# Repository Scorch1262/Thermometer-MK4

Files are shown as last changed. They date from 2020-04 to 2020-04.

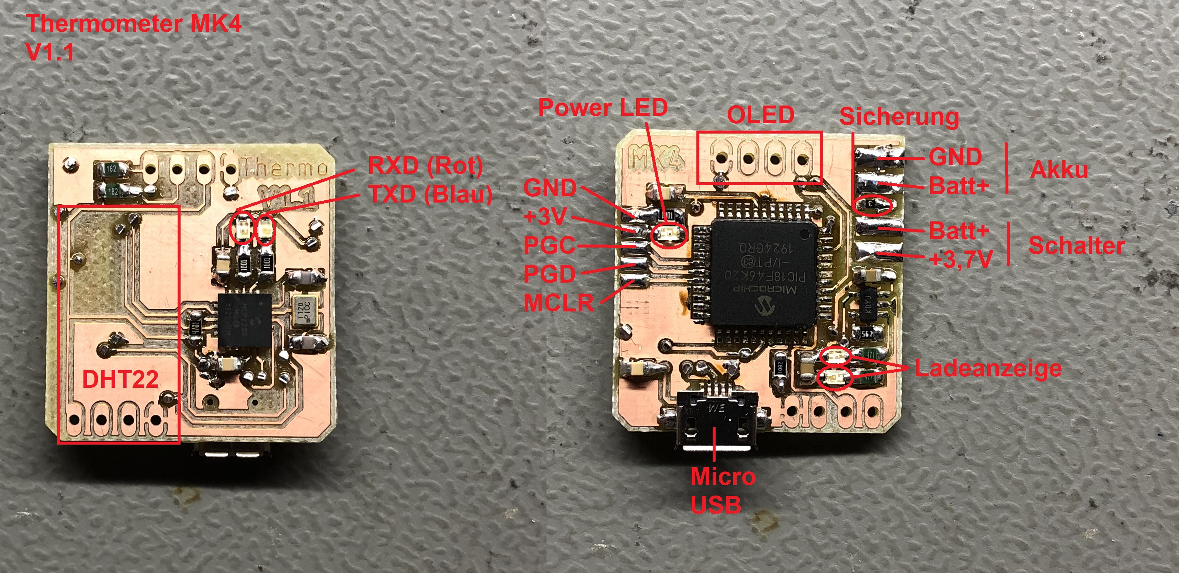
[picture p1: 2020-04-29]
Verkabelung V1.1.JPG

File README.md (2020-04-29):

Datenblatt

Status:				Fertig
Bezeichnung:			Thermometer MK4
Auftragsnummer:			
Auftraggeber:			Privat
Designer:			Torben Bott
Beschreibung:			Luftdruck und Themperatur Sensor mit OLED Anzeige, Lipo Akku und UART Schnittstelle 
			
Letzte Änderung:		23.04.2020

Versorgungsspannung (Normal):	5V
Versorgungsspannung (Min.):	5V
Versorgungsspannung (Max.):	5V
Interne Spannungen:		5V / 3,7V
		
Frequenz: 			16MHz
Prozessor: 			PIC18F46K20

Sensor:
https://github.com/jrmcguire/BME280

Display:
https://pic-projekte.de/blog/ssd1306/
https://github.com/PIC-Nico/SSD1306
https://pic-projekte.de/forum/viewtopic.php?f=3&t=104

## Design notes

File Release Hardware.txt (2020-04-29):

Hardware Release:

 Board (Hardware V1.1) [F]:
- PIC18F46K20
 - ISCP
- DHT22 Sensor
- LiPo Ladechip 
 - Status LEDs
- Power LED
- OLED-Display
- USB-UART Chip (MCP2200)
 - RXD LED
 - TXD LED
- Fehler behoben: Belegung DHT22
- Fehler behoben: UART Belegung

 Board (Hardware V1.0) [F]:
- PIC18F46K20
 - ISCP
- DHT22 Sensor
- LiPo Ladechip 
 - Status LEDs
- Power LED
- OLED-Display
- USB-UART Chip (MCP2200)
 - RXD LED
 - TXD LED

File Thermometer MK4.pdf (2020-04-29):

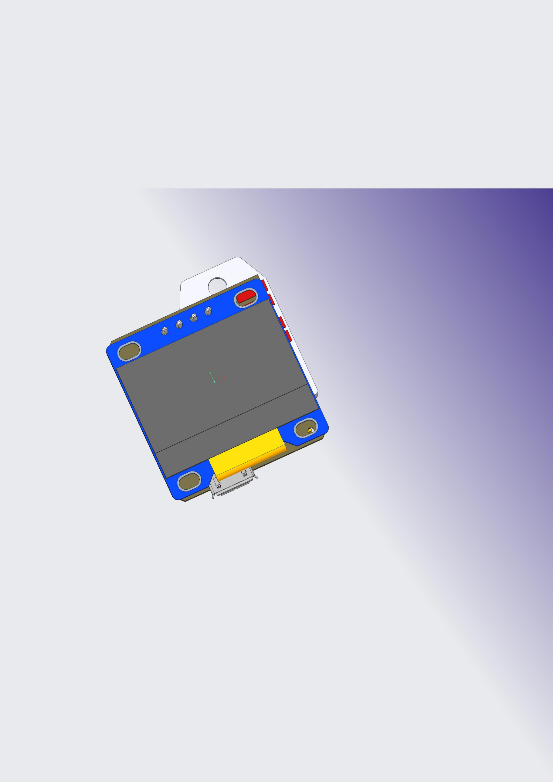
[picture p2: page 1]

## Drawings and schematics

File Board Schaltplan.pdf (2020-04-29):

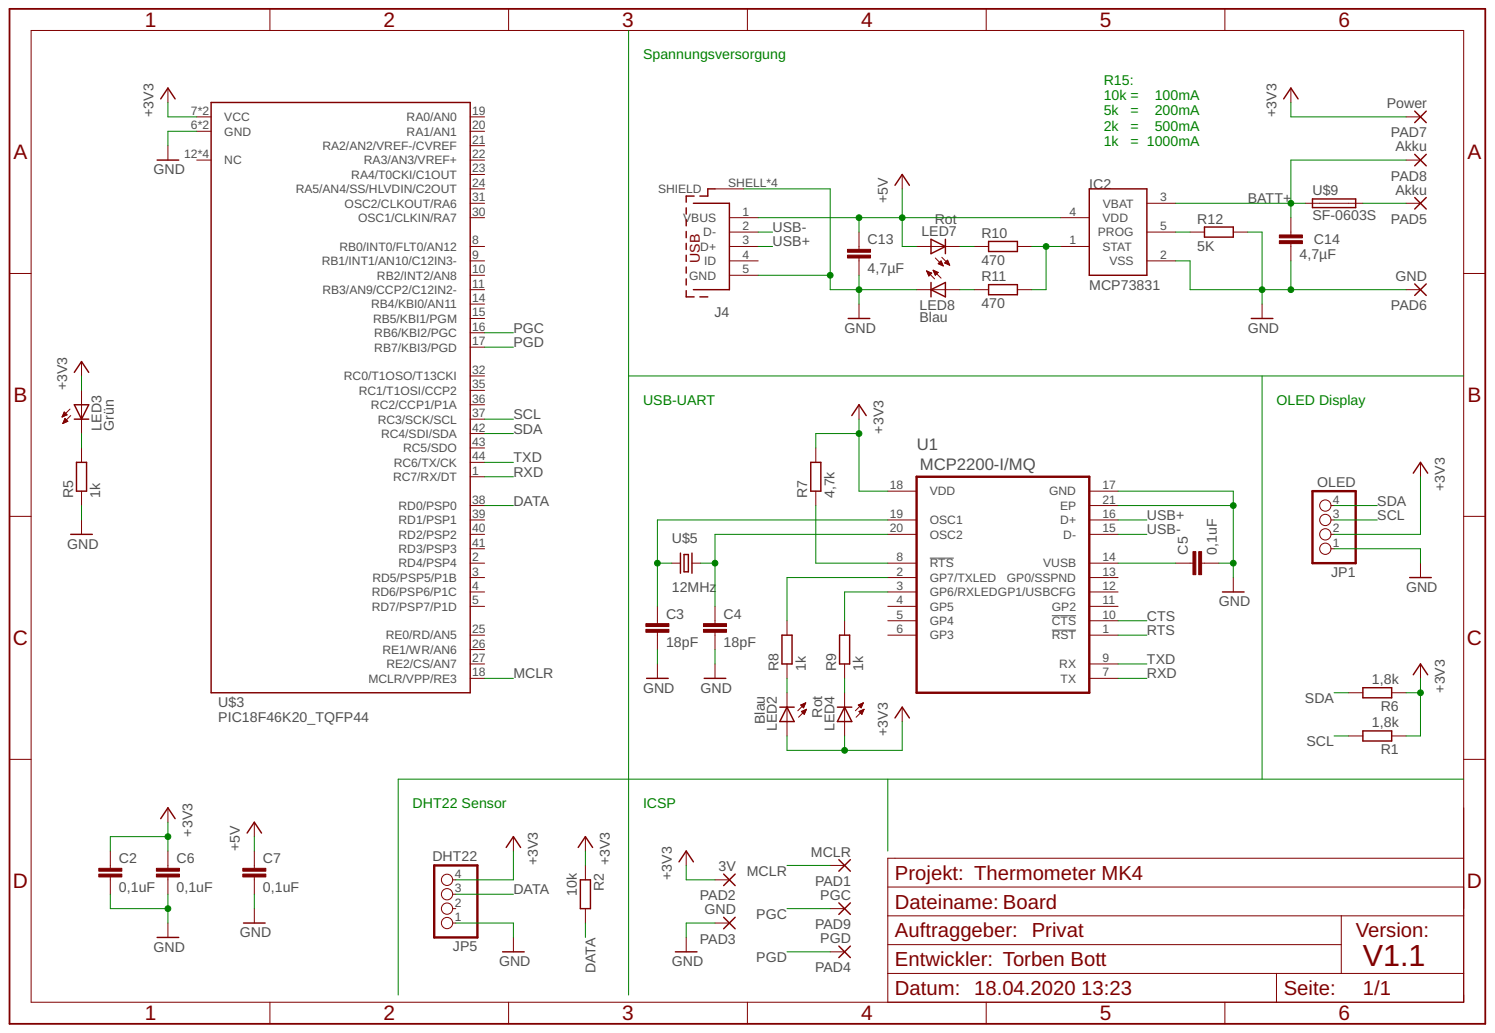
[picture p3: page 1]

Spannungsversorgung 2k = 500mA 1k = 1000mA

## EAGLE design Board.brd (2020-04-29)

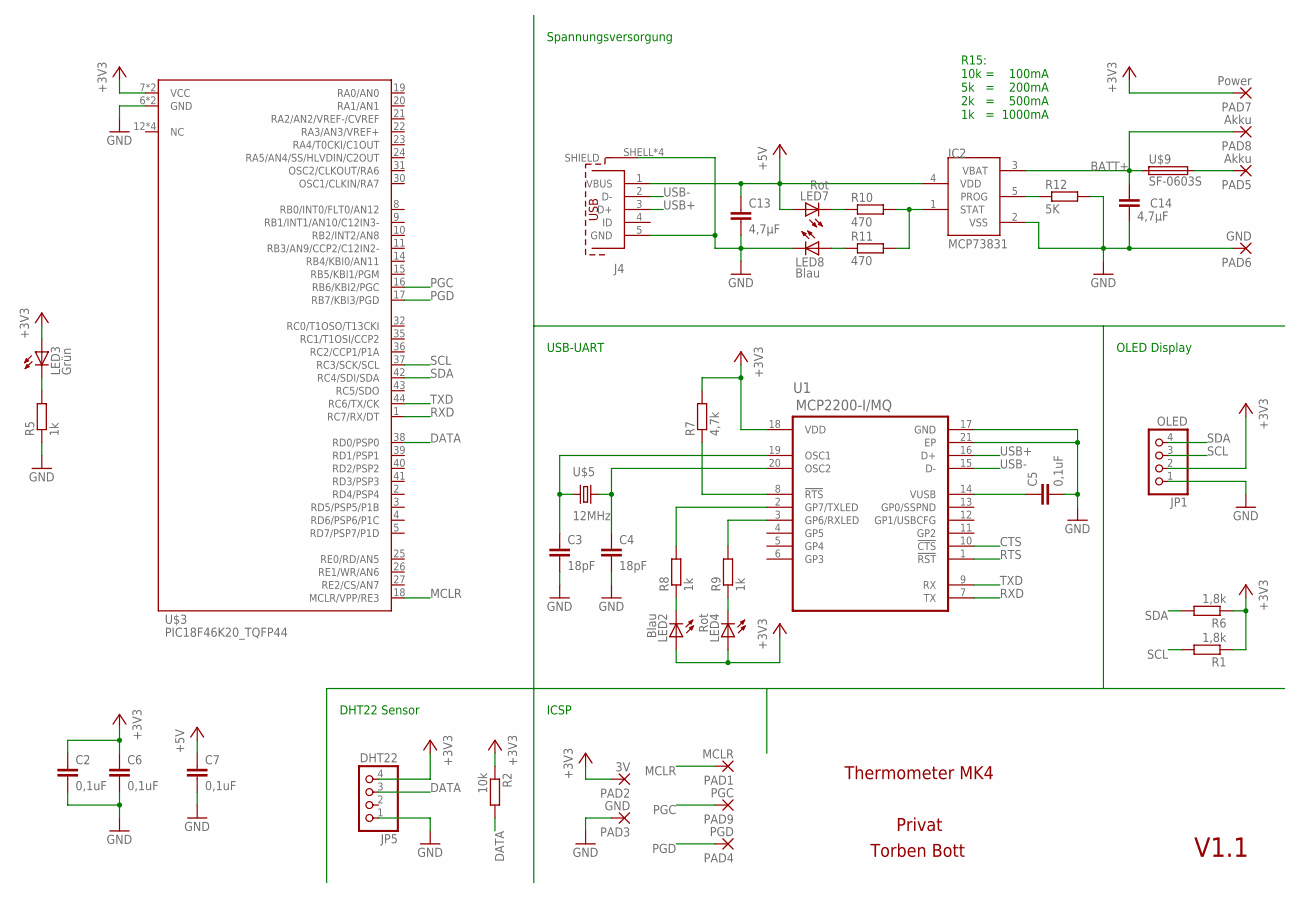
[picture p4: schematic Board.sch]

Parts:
C2, C5, C6, C7: 0,1uF; C0805
C3, C4: 18pF; C0805
C13, C14: 4,7µF; C0805
IC2: MCP73831; SOT23-5L
J4: 629105136821
JP1: OLED; 1X04
JP5: DHT22; 1X04
LED2, LED8: Blau; CHIPLED_0805
LED3: Grün; CHIPLED_0805
LED4, LED7: Rot; CHIPLED_0805
PAD1: MCLR; SMD1,27-2,54
PAD2: 3V; SMD1,27-2,54
PAD3: GND; SMD1,27-2,54
PAD4: PGD; SMD1,27-2,54
PAD5, PAD8: Akku; 5-1,8
PAD6: GND; 5-1,8
PAD7: Power; 5-1,8
PAD9: PGC; SMD1,27-2,54
R1, R6: 1,8k; R0805
R2: 10k; R0805
R5, R8, R9: 1k; R0805
R7: 4,7k; R0805
R10, R11: 470; R0805
R12: 5K; R0805
U1: MCP2200-I/MQ; QFN65P500X500X100-21N
U$3: PIC18F46K20_TQFP44; TQFP44
U$5: 12MHz; 7M_SERIES
U$9: SF-0603S; R0603

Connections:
+3V3: C2.1, C6.1, JP1.2, JP5.4, LED2.A, LED3.A, LED4.A, PAD2.1, PAD7.1, R1.1, R2.1, R6.1, R7.2, U1.18 (VDD), U$3.7 (VCC), U$3.28 (VCC)
+5V: C7.1, C13.1, IC2.4 (VDD), J4.1 (VBUS), LED7.A
BATT+: C14.1, IC2.3 (VBAT), PAD8.1, U$9.1
CTS: U1.10 (!CTS)
DATA: JP5.3, R2.2, U$3.38 (RD0/PSP0)
GND: C2.2, C3.2, C4.2, C5.2, C6.2, C7.2, C13.2, C14.2, IC2.2 (VSS), J4.5 (GND), J4.SHELL (SHIELD), J4.SHELL1 (SHIELD), J4.SHELL2 (SHIELD), J4.SHELL3 (SHIELD), JP1.1, JP5.1, LED8.C, PAD3.1, PAD6.1, R5.1, R12.2, U1.17 (GND), U1.21 (EP), U$3.6 (GND), U$3.29 (GND)
MCLR: PAD1.1, U$3.18 (MCLR/VPP/RE3)
unnamed: C4.1, U1.20 (OSC2), U$5.3 (2)
unnamed: LED3.C, R5.2
unnamed: C3.1, U1.19 (OSC1), U$5.1
unnamed: R7.1, U1.8 (!RTS)
unnamed: R8.2, U1.2 (GP7/TXLED)
unnamed: R9.2, U1.3 (GP6/RXLED)
unnamed: C5.1, U1.14 (VUSB)
unnamed: LED2.C, R8.1
unnamed: LED4.C, R9.1
unnamed: IC2.1 (STAT), R10.2, R11.2
unnamed: LED7.C, R10.1
unnamed: LED8.A, R11.1
unnamed: IC2.5 (PROG), R12.1
unnamed: PAD5.1, U$9.2
PGC: PAD9.1, U$3.16 (RB6/KBI2/PGC)
PGD: PAD4.1, U$3.17 (RB7/KBI3/PGD)
RTS: U1.1 (!RST)
RXD: U1.7 (TX), U$3.1 (RC7/RX/DT)
SCL: JP1.3, R1.2, U$3.37 (RC3/SCK/SCL)
SDA: JP1.4, R6.2, U$3.42 (RC4/SDI/SDA)
TXD: U1.9 (RX), U$3.44 (RC6/TX/CK)
USB+: J4.3 (D+), U1.16 (D+)
USB-: J4.2 (D-), U1.15 (D-)

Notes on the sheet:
Torben Bott
ICSP
OLED Display
Privat
V1.1
Thermometer MK4
Spannungsversorgung
R15: 10k = 100mA 5k = 200mA 2k = 500mA 1k = 1000mA
USB-UART
DHT22 Sensor

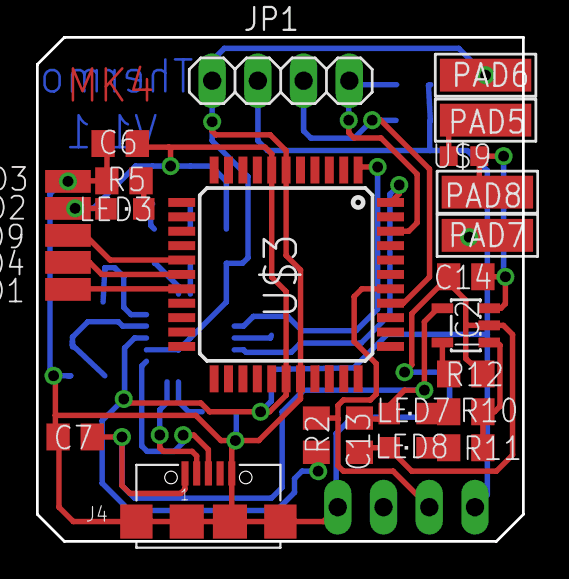
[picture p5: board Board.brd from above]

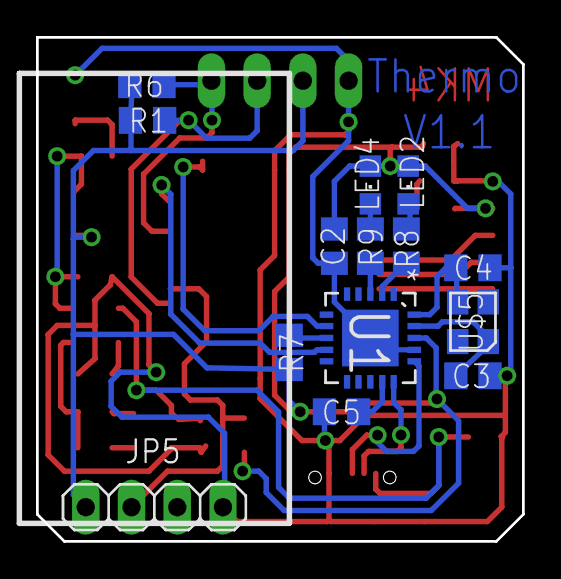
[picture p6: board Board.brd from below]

Board: 2 copper layers, 27.0 x 28.0 mm, 40 parts (14 on the bottom side), 28 nets.

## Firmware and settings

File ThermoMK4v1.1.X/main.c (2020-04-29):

/**
  Generated Main Source File

  Company:
    Microchip Technology Inc.

  File Name:
    main.c

  Summary:
    This is the main file generated using PIC10 / PIC12 / PIC16 / PIC18 MCUs

  Description:
    This header file provides implementations for driver APIs for all modules selected in the GUI.
    Generation Information :
        Product Revision  :  PIC10 / PIC12 / PIC16 / PIC18 MCUs - 1.80.0
        Device            :  PIC18F46K20
        Driver Version    :  2.00
*/

/*
    (c) 2018 Microchip Technology Inc. and its subsidiaries.

    Subject to your compliance with these terms, you may use Microchip software and any
    derivatives exclusively with Microchip products. It is your responsibility to comply with third party
    license terms applicable to your use of third party software (including open source software) that
    may accompany Microchip software.

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
    IN NO EVENT WILL MICROCHIP BE LIABLE FOR ANY INDIRECT, SPECIAL, PUNITIVE,
    INCIDENTAL OR CONSEQUENTIAL LOSS, DAMAGE, COST OR EXPENSE OF ANY KIND
    WHATSOEVER RELATED TO THE SOFTWARE, HOWEVER CAUSED, EVEN IF MICROCHIP
    HAS BEEN ADVISED OF THE POSSIBILITY OR THE DAMAGES ARE FORESEEABLE. TO
    THE FULLEST EXTENT ALLOWED BY LAW, MICROCHIP'S TOTAL LIABILITY ON ALL
    CLAIMS IN ANY WAY RELATED TO THIS SOFTWARE WILL NOT EXCEED THE AMOUNT
    OF FEES, IF ANY, THAT YOU HAVE PAID DIRECTLY TO MICROCHIP FOR THIS
    SOFTWARE.
*/

#include "mcc_generated_files/mcc.h"
#include <xc.h>
#include <stdlib.h>
#include <stdint.h>
#include <string.h>
#include <stdio.h>
#include "oled.h"
#include "peri.h"
#include "bmp.h"
#include "dht22.h"

extern char Temperature[];
extern char Humidity[];
extern unsigned char T_Byte1, T_Byte2, RH_Byte1, RH_Byte2, CheckSum ;
extern unsigned int Temp, RH;

/*
                         Main application
 */

void main(void){
    // Initialize the device
    SYSTEM_Initialize();                                                            //
    initI2C();                                                                      //
    oled_init();                                                                     // 

    // If using interrupts in PIC18 High/Low Priority Mode you need to enable the Global High and Low Interrupts
    // If using interrupts in PIC Mid-Range Compatibility Mode you need to enable the Global and Peripheral Interrupts
    // Use the following macros to:

    // Enable the Global Interrupts
    INTERRUPT_GlobalInterruptEnable();

    // Disable the Global Interrupts
    //INTERRUPT_GlobalInterruptDisable();

    // Enable the Peripheral Interrupts
    INTERRUPT_PeripheralInterruptEnable();

    // Disable the Peripheral Interrupts
    //INTERRUPT_PeripheralInterruptDisable();

    T1CON  = 0x20;                                                                  // set Timer1 clock source to internal with 1:4 prescaler (Timer1 clock = 1MHz)
    TMR1_Reload();                                                                  // setzt "TMR1" zur?ck// 

    fb_draw_string_big(0,0," Thermometer ");                                        // schreibt " Thermometer " an OLED
    fb_draw_string_big(44,2,"MK4");                                                 // schreibt "MK4" an OLED
    fb_draw_string(230,6,"V1.1");                                                   // schreibt "V1.0" an OLED
    fb_show();                                                                      // Den Framebuffer zur Anzeige bringen
    __delay_ms(1000);                                                               // wartet 1000ms
    fb_clear();                                                                     // 
    
    while (1){                                                                      // Endlosschleife
        Start_Signal();                                                             // ruft "Start_Signal" (DHT22) auf
        if(Check_Response()){                                                       // wenn "Check_Response" gleich "true"
            if(Read_Data(&RH_Byte1) || Read_Data(&RH_Byte2) || Read_Data(&T_Byte1) || Read_Data(&T_Byte2) || Read_Data(&CheckSum)){ // 
                printf("Time out!\r\n");                                            // schreibt "Time out!\r\n" an UART
                fb_draw_string_big(10,3,"Time");                                    // schreibt inhalte von "Time" an OLED
                fb_draw_string_big(10,5,"Out!");                                    // schreibt inhalte von "Out!" an OLED
                fb_show();                                                          // Den Framebuffer zur Anzeige bringen
            }else{                                                                  // sonst
                if(CheckSum == ((RH_Byte1 + RH_Byte2 + T_Byte1 + T_Byte2) & 0xFF)){ // ?berpr?fung der "CheckSum"
                    RH = RH_Byte1;                                                  // "RH" gleich "RH_Byte1"
                    RH = (RH << 8) | RH_Byte2;                                      //
                    Temp = T_Byte1;                                                 // "Temp" gleich "T_Byte1"
                    Temp = (Temp << 8) | T_Byte2;                                   // 

                    if(Temp > 0X8000){                                              // wenn "Temp" gr??er als "0X8000"
                        Temperature[0] = '-';                                       // "Temperature" stelle 6 gleich "-"
                        Temp = Temp & 0X7FFF;                                       // "Temp" gleich "Temp" UND 0X7FFF
                    }else{                                                          // sonst
                        Temperature[0]  = ' ';                                      // "Temperature" stelle 3 gleich " "
                        Temperature[1]  = (Temp / 100) % 10  + '0';                 // "Temperature" stelle 4
                        Temperature[2]  = (Temp / 10) % 10   + '0';                 // "Temperature" stelle 5
                        Temperature[4]  =  Temp % 10  + '0';                        // "Temperature" stelle 7
                    }                                                               //
                    if(RH == 1000){                                                 // wenn "RH" gleich 1000 ist
                        Humidity[0]  = 1 + '0';                                     // "Humidity" stelle 3 gleich 1 + "0" 
                    }else{                                                          // sonst
                        Humidity[0]  = ' ';                                         // "Humidity" stelle 3 gleich " "
                        Humidity[1]  = (RH / 100) % 10 + '0';                       // "Humidity" stelle 4
                        Humidity[2]  = (RH / 10) % 10  + '0';                       // "Humidity" stelle 5
                        Humidity[4]  = RH % 10 + '0';                               // "Humidity" stelle 7
                    }                                                               //
                    
                    printf("Temperatur: ");                                         // schreibt "Temperatur: " an UART
                    printf(Temperature);                                            // schreibt inhalte von "Temperature" an UART
                    printf("\t");                                                   // schreibt Tab an UART
                    printf("Feuchtigkeit: ");                                       // schreibt "Feuchtigkeit: " an UART
                    printf(Humidity);                                               // schreibt inhalte von "Humidity" an UART
                    printf("\r");                                                   // setzt die Ziel zurück
                    
                    fb_draw_string_big(0,0," Thermometer ");                        // schreibt inhalte von "Temperature" an OLED
                    fb_draw_string_big(15,3,Temperature);                           // schreibt inhalte von "Temperature" an OLED
                    fb_draw_string_big(15,6,Humidity);                              // schreibt inhalte von "Humidity" an OLED
                    fb_draw_string(10,2,"Temperatur:");                             // schreibt "Temperatur" an OLED
                    fb_draw_string(10,5,"Feuchtigkeit:");                           // schreibt "Feuchtigkeit" an OLED
                    fb_show();                                                      // Den Framebuffer zur Anzeige bringen

                }else{                                                              // sonst
                    printf("Checksum Error!\r\n");                                  // schreibt "Checksum Error!\r\n" an UART
                    fb_draw_string_big(10,3,"Checksum");                            // schreibt inhalte von "Checksum" an OLED
                    fb_draw_string_big(10,5,"Error!");                              // schreibt inhalte von "Error!" an OLED
                    fb_show();                                                      // Den Framebuffer zur Anzeige bringen
                }                                                                   //
            }                                                                       //
        }else{                                                                      // sonst
            printf("No response from the sensor\r\n");                              // schreibt "No response from the sensor\r\n" an UART
            fb_draw_string_big(10,3,"No response");                                 // schreibt inhalte von "No response" an OLED
                    fb_draw_string_big(10,5,"from Sensor");                         // schreibt inhalte von "from Sensor" an OLED
                    fb_show();                                                      // Den Framebuffer zur Anzeige bringen
        }                                                                           //
        TMR1_StopTimer();                                                           // stoppt "TMR1" 
        __delay_ms(1000);                                                           // warte 1000ms
    }                                                                               //
}                                                                                   //
/**
 End of File
*/

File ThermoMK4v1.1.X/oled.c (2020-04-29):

/*******************************************************************************
 * File:        oled.c
 * Project:     SP18 - I2C OLED Display
 * Author:      Nicolas Pannwitz
 * Version:
 * Web:         http://pic-projekte.de
 ******************************************************************************/

#include <xc.h>
#include <stdint.h>
#include "oled.h"
#include "peri.h"
#include "font.h"

/*******************************************************************************
 * Framebuffer
 */

uint8_t buffer[1024];

/*******************************************************************************
 * Initialisierung des OLED-Displays
 */

void oled_init(void){
    //i2c.init(SSD1306_DEFAULT_ADDRESS);

    // Turn display off
    oled_sendCommand(SSD1306_DISPLAYOFF);

    oled_sendCommand(SSD1306_SETDISPLAYCLOCKDIV);
    oled_sendCommand(0x80);

    oled_sendCommand(SSD1306_SETMULTIPLEX);
    oled_sendCommand(0x3F);

    oled_sendCommand(SSD1306_SETDISPLAYOFFSET);
    oled_sendCommand(0x00);

    oled_sendCommand(SSD1306_SETSTARTLINE | 0x00);

    // We use internal charge pump
    oled_sendCommand(SSD1306_CHARGEPUMP);
    oled_sendCommand(0x14);

    // Horizontal memory mode
    oled_sendCommand(SSD1306_MEMORYMODE);
    oled_sendCommand(0x00);

    oled_sendCommand(SSD1306_SEGREMAP | 0x01);

    oled_sendCommand(SSD1306_COMSCANDEC);

    oled_sendCommand(SSD1306_SETCOMPINS);
    oled_sendCommand(0x12);

    // Max contrast
    oled_sendCommand(SSD1306_SETCONTRAST);
    oled_sendCommand(0xCF);

    oled_sendCommand(SSD1306_SETPRECHARGE);
    oled_sendCommand(0xF1);

    oled_sendCommand(SSD1306_SETVCOMDETECT);
    oled_sendCommand(0x40);

    oled_sendCommand(SSD1306_DISPLAYALLON_RESUME);

    // Non-inverted display
    oled_sendCommand(SSD1306_NORMALDISPLAY);

    // Turn display back on
    oled_sendCommand(SSD1306_DISPLAYON);
}

/*******************************************************************************
 * Übertragen eines Befehls an das OLED-Display
 */

void oled_sendCommand(uint8_t command){
    startI2C();
    sendI2C(SSD1306_DEFAULT_ADDRESS);

    sendI2C(0x00);
    sendI2C(command);

    stopI2C();
}

/*******************************************************************************
 * Invertierung des OLED-Display
 */

void oled_invert(uint8_t inverted){
    if (inverted){
        oled_sendCommand(SSD1306_INVERTDISPLAY);
    }else{
        oled_sendCommand(SSD1306_NORMALDISPLAY);
    }
}

/*******************************************************************************
 * Übertragen des Framebuffers an das OLED-Display
 */

void oled_sendFramebuffer(uint8_t *buffer){
    oled_sendCommand(SSD1306_COLUMNADDR);
    oled_sendCommand(0x00);
    oled_sendCommand(0x7F);

    oled_sendCommand(SSD1306_PAGEADDR);
    oled_sendCommand(0x00);
    oled_sendCommand(0x07);

    // We have to send the buffer as 16 bytes packets
    // Our buffer is 1024 bytes long, 1024/16 = 64
    // We have to send 64 packets

    for (uint8_t packet = 0; packet < 64; packet++){
        startI2C();
        sendI2C(SSD1306_DEFAULT_ADDRESS);
        sendI2C(0x40);

        for (uint8_t packet_byte = 0; packet_byte < 16; ++packet_byte){
            sendI2C(buffer[packet*16+packet_byte]);
        }

        stopI2C();
    }
}

/*******************************************************************************
 * Zeichnen eines Pixels in den Framebuffer an die Position (pos_x|pos_y).
 * Setzten des Pixels mit pixel_status = 1, loeschen mit pixel_status = 0
 */

void fb_drawPixel(uint8_t pos_x, uint8_t pos_y, uint8_t pixel_status){
    if (pos_x >= SSD1306_WIDTH || pos_y >= SSD1306_HEIGHT){
        return;
    }

    if (pixel_status){
        buffer[pos_x+(pos_y/8)*SSD1306_WIDTH] |= (1 << (pos_y&7));
    }else{
        buffer[pos_x+(pos_y/8)*SSD1306_WIDTH] &= ~(1 << (pos_y&7));
    }
}

/*******************************************************************************
 * Zeichnen einer vertikalen Linie in den Framebuffer von (x,y) der Laenge
 * length.
 */

void fb_drawVLine(uint8_t x, uint8_t y, uint8_t length){
    for (uint8_t i = 0; i < length; ++i){
        fb_drawPixel(x, i+y, 1);
    }
}

/*******************************************************************************
 * Zeichnen einer horizontalen Linie in den Framebuffer von (x|y) der Laenge
 * length.
 */

void fb_drawHLine(uint8_t x, uint8_t y, uint8_t length){
    for (uint8_t i = 0; i < length; ++i){
        fb_drawPixel(i+x, y, 1);
    }
}

/*******************************************************************************
 * Zeichnen eines Rechtecks in den Framebuffer von (x1|y1) zu (x2|y2).
 * Das Rechteck kann gefuellt werden (1 = fill) oder leer sein (0 = fill).
 */

void fb_drawRectangle(uint8_t x1, uint8_t y1, uint8_t x2, uint8_t y2, uint8_t fill){
    uint8_t length = x2 - x1 + 1;
    uint8_t height = y2 - y1;

    if (!fill){
        fb_drawHLine(x1, y1, length);
        fb_drawHLine(x1, y2, length);
        fb_drawVLine(x1, y1, height);
        fb_drawVLine(x2, y1, height);
    }else{
        for (int x = 0; x < length; ++x){
            for (int y = 0; y <= height; ++y){
                fb_drawPixel(x1+x, y+y1, 1);
            }
        }
    }
}

/*******************************************************************************
 * Löschen des Framebuffers
 */

void fb_clear(){
    for (uint16_t buffer_location = 0; buffer_location < SSD1306_BUFFERSIZE; buffer_location++){
        buffer[buffer_location] = 0x00;
    }
}

/*******************************************************************************
 * Invertieren des Framebuffers
 */

void fb_invert(uint8_t status){
    oled_invert(status);
}

/*******************************************************************************
 * Darstellen des Framebuffers auf dem OLED-Display
 */

void fb_show(){
    oled_sendFramebuffer(buffer);
}

void fb_show_bmp(uint8_t *pBmp){
    oled_sendFramebuffer(pBmp);
}

void fb_show_background(uint8_t *pBmp){
    pBmp = pBmp || buffer;
    oled_sendFramebuffer(pBmp);
}

/*******************************************************************************
 * Zeichnen eines Zeichens an Position (x,y) - Diese Funktion kann nur indirekt
 * mit Hilfe der Funktion oled_draw_string aufgerufen werden, da diese den
 * entsprechenden Index fuer den font-Vector berechnet!
 */

void fb_draw_char (uint16_t x, uint16_t y, uint16_t fIndex){
    uint16_t bufIndex = (y << 7) + x;
    uint8_t j;

    for(j=0; j < FONT_WIDTH; j++){
        buffer[bufIndex + j] = font[fIndex + j + 1];
    }
}

/*******************************************************************************
 * Zeichnen einer Zeichenkette ab Position (x,y)
 */
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

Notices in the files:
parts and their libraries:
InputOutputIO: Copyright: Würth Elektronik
